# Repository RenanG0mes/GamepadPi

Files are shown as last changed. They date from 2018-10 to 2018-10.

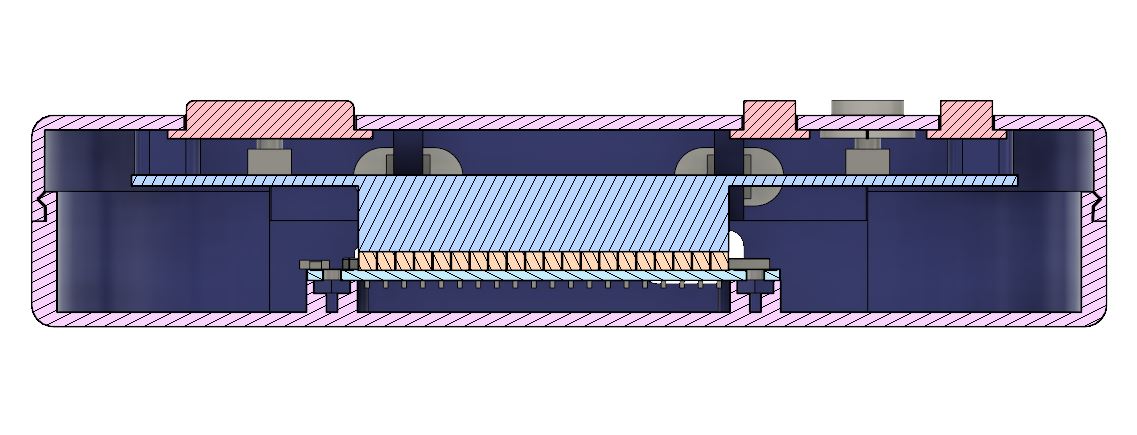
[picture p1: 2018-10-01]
General pictures/01c - 3D printed - Section 1.JPG

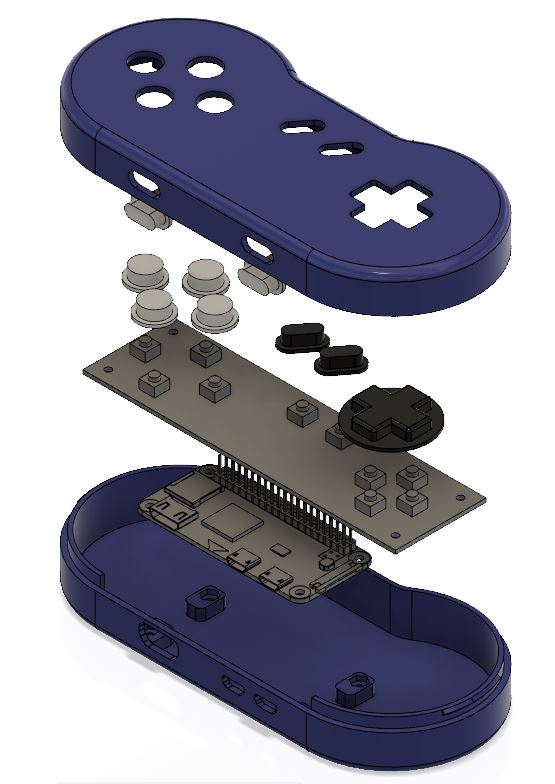
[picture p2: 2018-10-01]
General pictures/01b - 3D printed - General vision.jpg

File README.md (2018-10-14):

# GamepadPi
A functional emulation device made with Raspberry Pi Zero 

**Materials used**
	
	- Raspberry Pi Zero W
	- Copper clad board (if you don't have access to a cnc milling machine you can probably improvise with one of these already perforated prototyping boards)
	- 12 tactile switches (6mm x 6 mm)
	- 2x20 male header
	- 2x20 female header
	- 8 screws (M2 x 5mm) (and maybe M2 nuts)
	
**Equipment Used**
	
	- 3D printer and filament
	- PCB cnc milling machine
	- PCB soldering equipment
	- Some sandpaper

**Instructions**

	1 - Printing the gamepad case
	
	The 3D CAD files can be found in the folder "3D CAD files", the drawings were made using Fusion 360 software and the files are available in .f3d and .step. Use your preferred slicer to generate the files for you 3D printer.
	There is a second option which is a smaller, wooden made, version of the case, files can be found in this same folder.
	
	2 - Gamepad PCB board
	
	The gerber files to mill the board can be found in the folder "PCB board". If you don't have access to a cnc milling machine you can probably improvise with one of these already perforated prototyping boards, but you're going to have to figure out how to place buttons at the right distances one to another.
	The files for the smaller version of the gamepad can be found here too.
	The tactile switches should be soldered at one of the sides of the board and the female header should be soldered to the opposite side.
	Jumper cables were used to connect the shoulder buttons to the board.
	The male header should be soldered to the Raspberry Pi Zero.
	Pictures of the soldering can be found at the "General pictures" folder
	
 	3 - Mounting
 
 	Use the screws to fix the Raspberry Pi to the bottom of the case and the PCB board to the top of the case (don't forget to put the buttons first). Depending on the kind of screws you are using, if you can't get the threads of the screws inside de plastic you can use some instant glue to glue nuts into the holes of the fixing points and then attach the screws to the nuts.
 	After mounting it all you should put the top and bottom together, the two headers should connect.
 	As my 3D printing job was not very good, it was necessary to use sandpaper to smooth some imperfections so the two pieces of the case could snap together and the buttons work correctly.
	
	4 - Installing and configuring the system
		
		(Instruction for Ubuntu distribution)
		
		4.1 - Installing retropie
		Download retropie image from https://retropie.org.uk/download/
		
		Extract: 
			gunzip retropie-4.X.X-rpi2_rpi3.img.gz  (X corresponds to the version you downloaded)
			
		4.2 - Discover the SD card mount point
		Run "lsblk" to see which devices are currently connected to your machine.
		Insert the SD card into an SD card reader, then connect the reader to your computer.
		Run "lsblk" again. The new device that has appeared is your SD card.
		If any partitions on the SD card have been mounted, unmount them all with "umount", for example "umount /dev/sdX1"
		
		4.3 - Copy the image to SD card using "dd" command.
			sudo dd bs=4M if=NAMEOFTHERETROPIEIMAGE.img of=/dev/sdX status=progress conv=fsync
			
		4.4 - Run "sync" and remove
		Run "sync". This will ensure that the write cache is flushed and that it is safe to unmount your SD card.
		Remove the SD card from the card reader.
		
		4.5 (optional) - Enable SSH and connect to Wi-Fi
		If you have a micro usb to usb adapter, you can connect a keyboard and mouse and skip this part, if you don't we're gonna have to enable SSH and connect to a wi-fi network so we will be able to control our raspberry pi through another machine.
		
		To enable SSH create an empty file, WITH NO EXTENSION in the boot directory called "ssh".
		
		To connect to a wi-fi network create a file named "wpa_supplicant.conf", the content of this file should be as it follows (change your country and network credentials):
		
		country=BR
		ctrl_interface=DIR=/var/run/wpa_supplicant GROUP=netdev
		update_config=1
		network={
			ssid="MyWiFiNetwork"
			psk="YourPassword"
			key_mgmt=WPA-PSK
		}
		
		Now your raspberry pi will connect to the wi-fi network and you can control it via SSH.
		
		4.6 - Installing adafruit's retrogame
		Install adafruit's retrogame library running the commands bellow:
		
		cd
		curl https://raw.githubusercontent.com/adafruit/Raspberry-Pi-Installer-Scripts/master/retrogame.sh >retrogame.sh
		sudo bash retrogame.sh
		
		Select "Super Game Pi"
		
		More info can be found at: https://learn.adafruit.com/retro-gaming-with-raspberry-pi?view=all#adding-controls-software
		
		Use nano to edit /boot/retrogame.cfg
		The file retrogame.cfg should be as it follows:
		
		# Sample configuration file for retrogame.
		# Really minimal syntax, typically two elements per line w/space delimiter:
		# 1) a key name (from keyTable.h; shortened from /usr/include/linux/input.h).
		# 2) a GPIO pin number; when grounded, will simulate corresponding keypress.
		# Uses Broadcom pin numbers for GPIO.
		# If first element is GND, the corresponding pin (or pins, multiple can be
		# given) is a LOW-level output; an extra ground pin for connecting buttons.
		# A '#' character indicates a comment to end-of-line.
		# File can be edited "live," no need to restart retrogame!

		# Here's a pin configuration for the Super Game Pi project:

		LEFT      20  # Joypad left
		RIGHT     26  # Joypad right
		UP        19  # Joypad up
		DOWN      21  # Joypad down
		Z         25  # 'A' button
		X         24  # 'B' button
		ESC       12  # 'Select' button
		ENTER     16  # 'Start' button
		S          5  # 'X' button
		A         23  # 'Y' button
		Q         13  # Left shoulder button
		W          6  # Right shoulder button

		# For configurations with few buttons (e.g. Cupcade), a key can be followed
		# by multiple pin numbers.  When those pins are all held for a few seconds,
		# this will generate the corresponding keypress (e.g. ESC to exit ROM).
		# Only ONE such combo is supported within the file though; later entries
		# will override earlier.
		
		4.7 - Playing
		Now you can reboot your raspberry pi, plug it to a monitor, add your favorite ROMs and have fun.

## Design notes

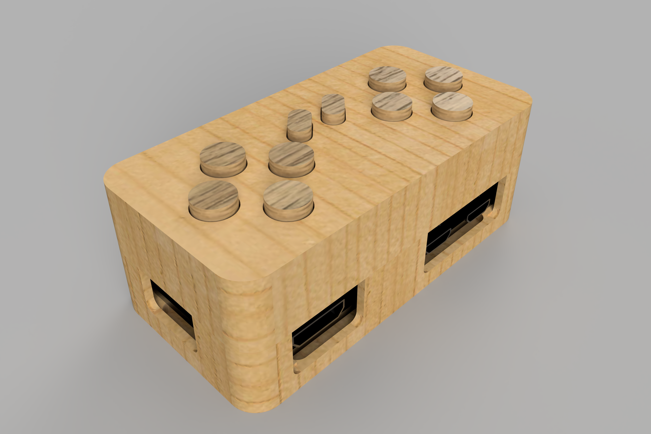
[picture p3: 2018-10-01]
General pictures/Wooden made Render1.png

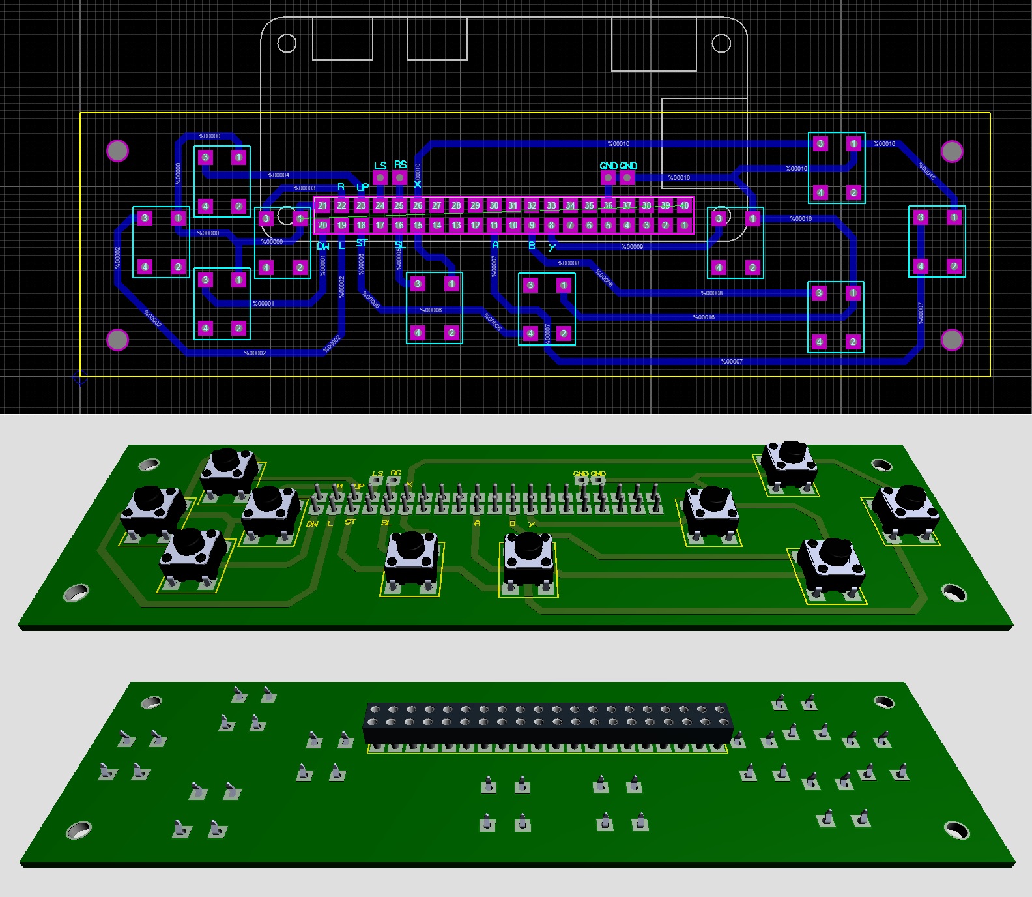
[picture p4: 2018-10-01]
General pictures/01d - PCB board - drawing.jpg

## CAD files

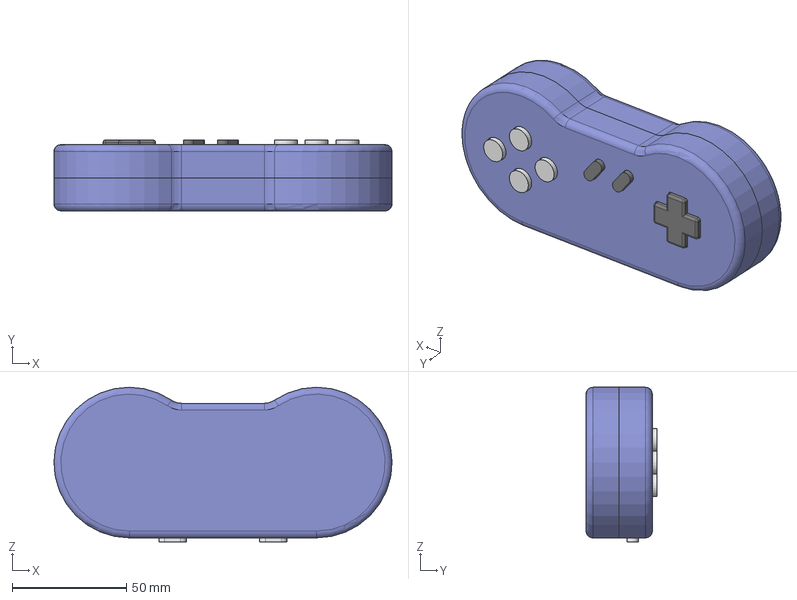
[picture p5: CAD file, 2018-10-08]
3D CAD files/3D printed.step
147.9 x 31.0 x 67.6 mm
RaspberryPiZeroW
Header Male
PCB with buttons
Buttons

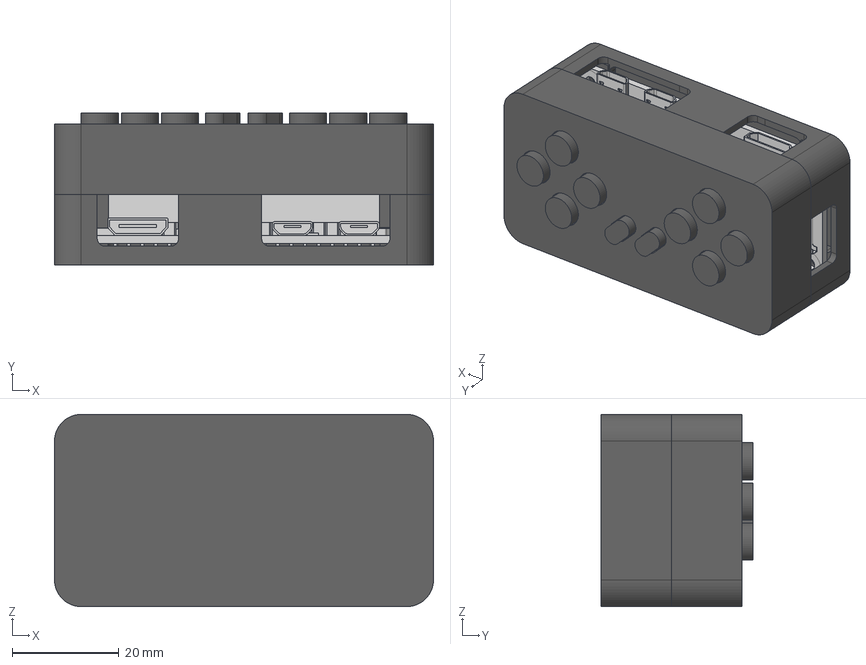
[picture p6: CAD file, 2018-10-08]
3D CAD files/Wooden made (mini version).step
71.0 x 28.4 x 36.0 mm
Board
RaspberryPiZeroW
Header Male v1
Case
Botões

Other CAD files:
3D CAD files/3D printed.f3d
3D CAD files/Wooden made (mini version).f3d

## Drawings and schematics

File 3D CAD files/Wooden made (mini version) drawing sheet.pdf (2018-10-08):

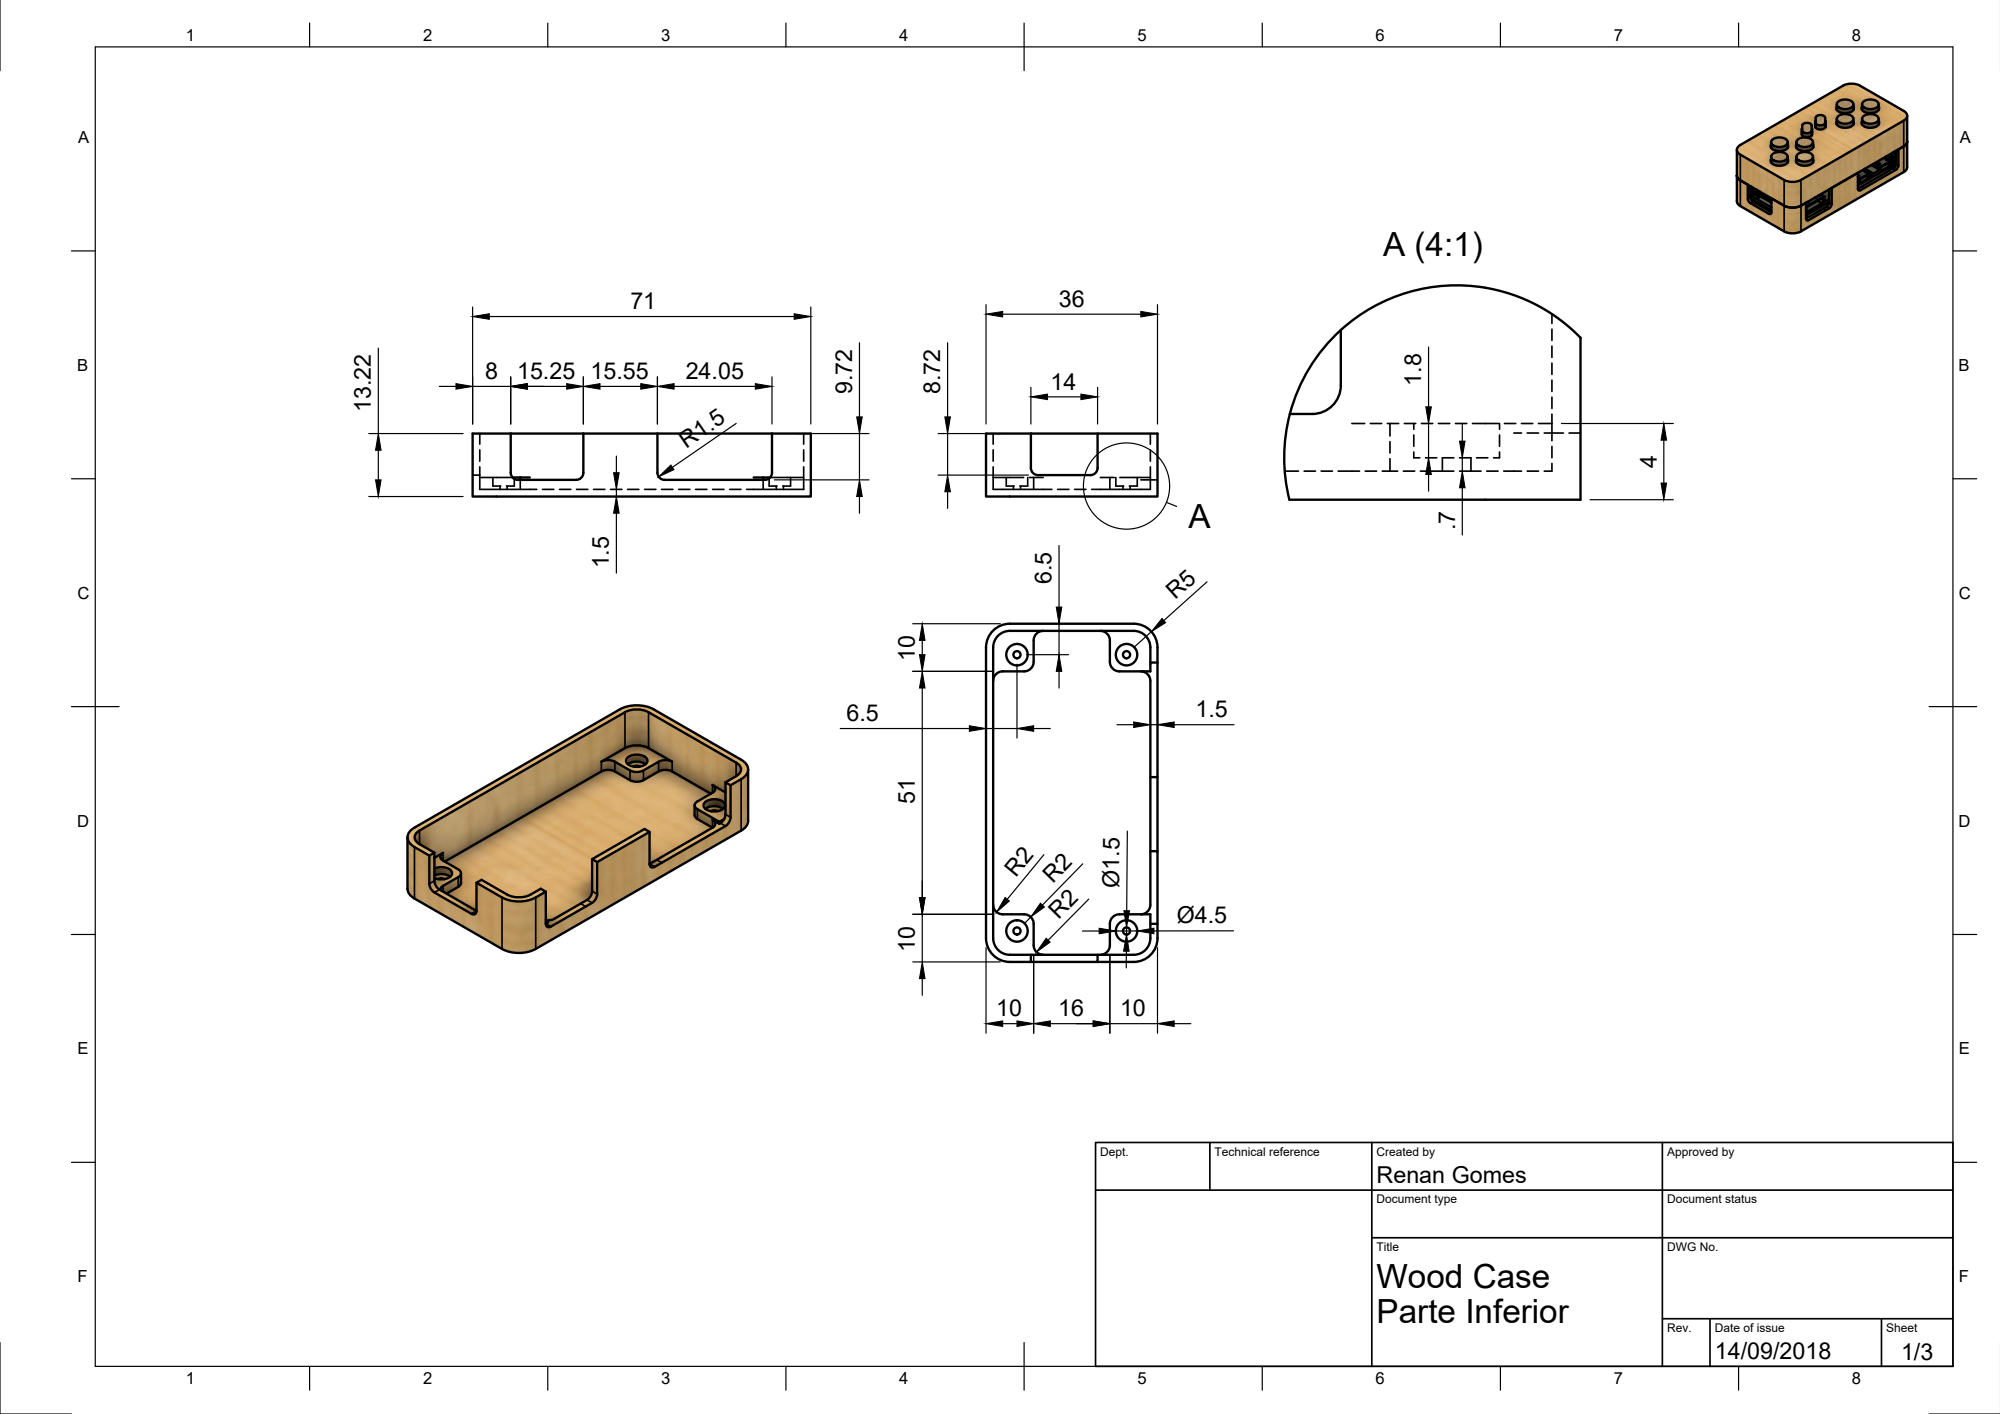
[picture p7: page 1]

Dept. | Technical reference | Created by Renan Gomes | Approved by

Document type | Document status

Title Wood Case Parte Inferior | DWG No.

Rev. | Date of issue 14/09/2018 | Sheet 1/3

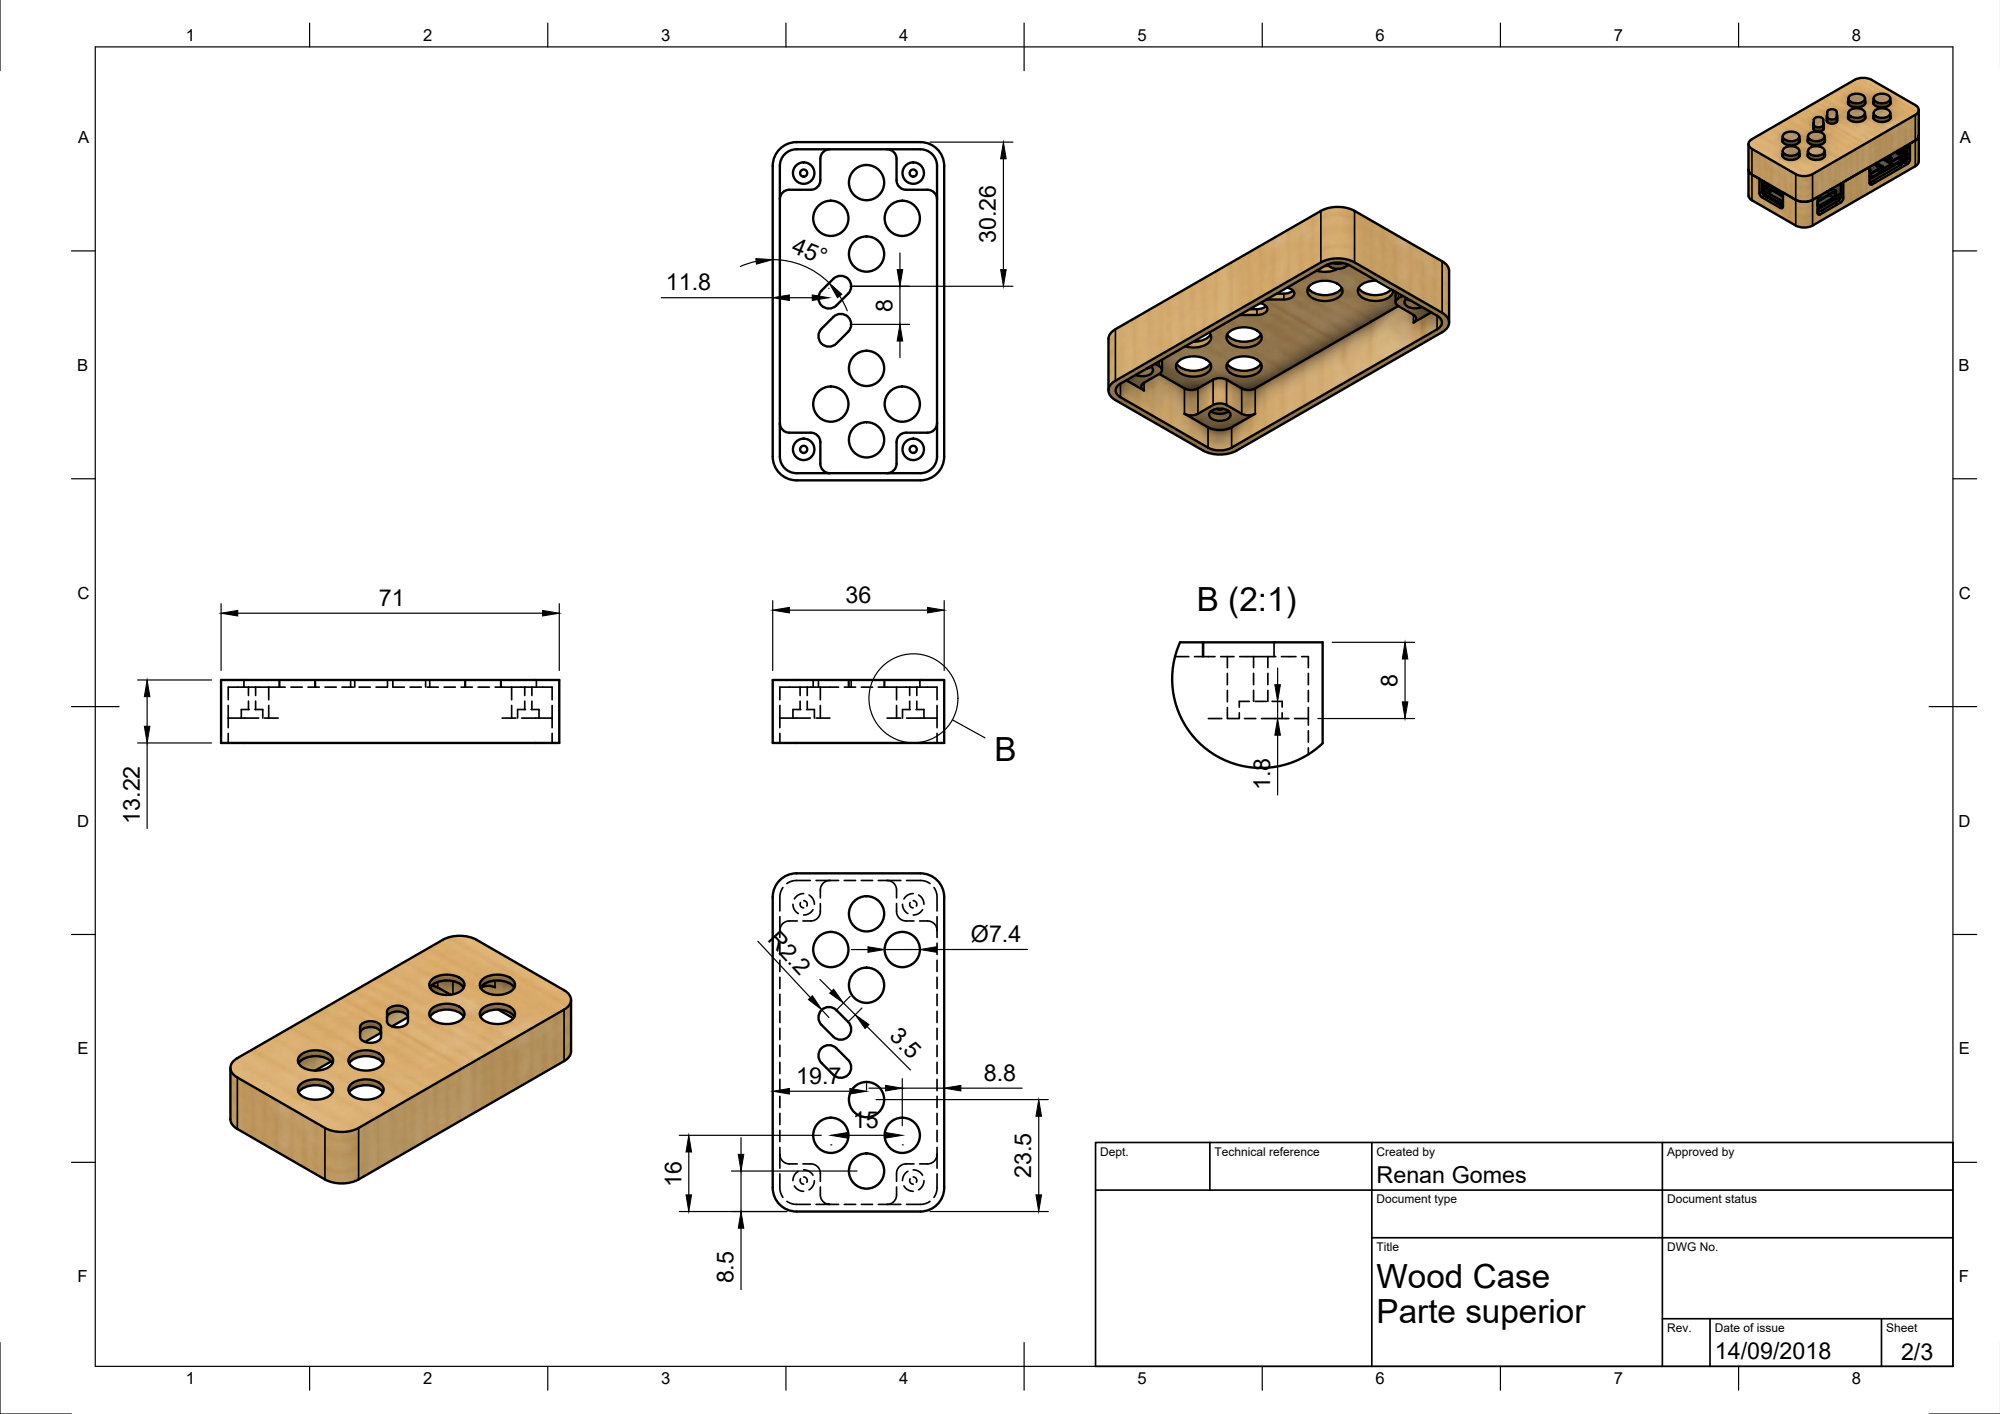
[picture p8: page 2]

Dept. | Technical reference | Created by Renan Gomes | Approved by

Document type | Document status

Title Wood Case Parte superior | DWG No.

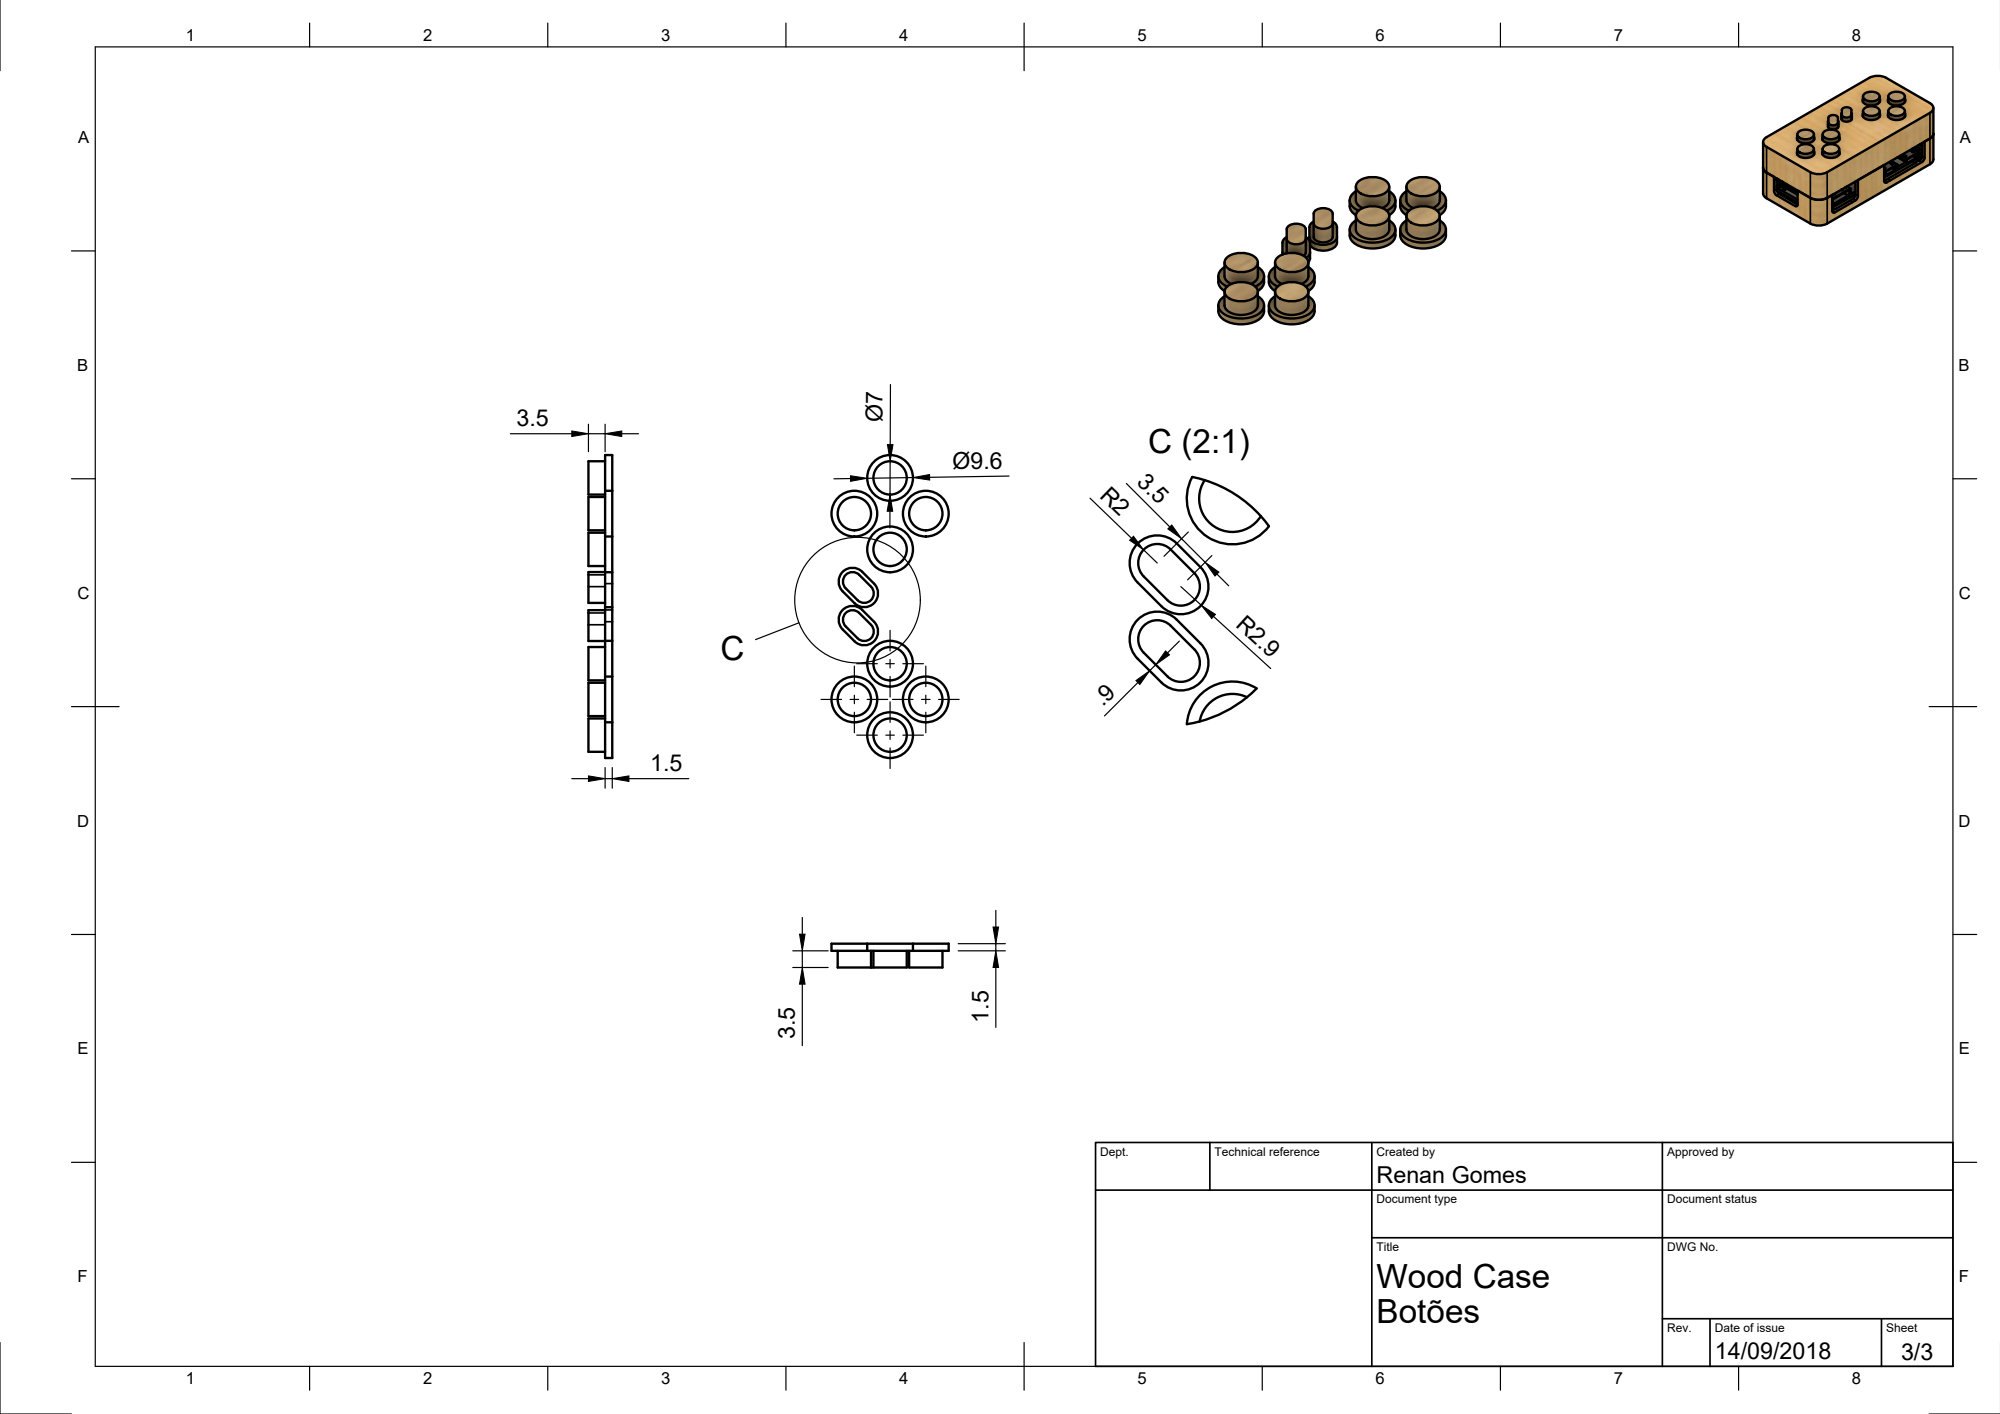
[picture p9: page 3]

Dept. | Technical reference | Created by Renan Gomes | Approved by

Document type | Document status

Title Wood Case Botões | DWG No.

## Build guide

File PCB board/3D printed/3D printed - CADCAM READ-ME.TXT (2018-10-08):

LABCENTER PROTEUS TOOL INFORMATION FILE
=======================================

In case of difficulty, please e-mail support@labcenter.co.uk

Tool set up for Proteus layout 'Board.pdsprj'.
CADCAM generated at 12:10:15 on segunda-feira, 8 de outubro de 2018.

File List
---------
Bottom Copper           : 3D printed - CADCAM Bottom Copper.GBR
Top Silk Screen         : 3D printed - CADCAM Top Silk Screen.GBR
Drill, Plated, 1-16     : 3D printed - CADCAM Drill L1 L16 Plated.GBR
Netlist                 : 3D printed - CADCAM Netlist.IPC

Photoplotter Setup
------------------
Format: X2, ASCII, 4.3, metric, absolute, eob=*, LZO
Notes:  D=Diameter, S=Side, W=Width, H=Height, C=Chamfer, I=Index

D10	CIRCLE  D=1mm                                                             DRAW  Conductor
D11	SQUARE  S=2.032mm                                                         FLASH ComponentPad
D12	SQUARE  S=2mm                                                             FLASH ComponentPad
D13	CIRCLE  D=3.048mm                                                         FLASH ComponentPad
D14	CIRCLE  D=0.2032mm                                                        DRAW  Profile
D15	CIRCLE  D=0.2032mm                                                        DRAW  Material
D16	CIRCLE  D=1.016mm                                                         FLASH ComponentDrill
D17	CIRCLE  D=1mm                                                             FLASH ComponentDrill
D18	CIRCLE  D=2.49936mm                                                       FLASH ComponentDrill

[END OF FILE]

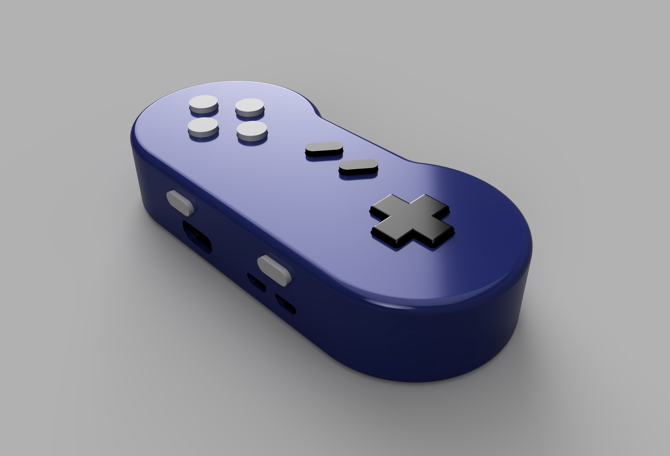
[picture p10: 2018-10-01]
General pictures/01a - 3D printed - Render 1.png
